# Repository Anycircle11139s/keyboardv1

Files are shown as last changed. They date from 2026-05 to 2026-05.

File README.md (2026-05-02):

# keyboardv1
For hack club stasis, I have to journal a lot, and when I journal, I'm locked in, I just keep on typing and typing until I realise that my hands ache like hell because of my uncomfortable keyboard. Because of this, I decided to make myself a customisable 65% keyboard that I can use for playing games (I can customise the keys and make different modes for what I'm doing), journal and all my other typing needs. I created a keyboard matrix for the schematic and placed all my keys into a specific format in the pcb along with making some stablisation holes for space bars and other keycaps. I also added some tuff af silkscreen to the PCB. For the case, I designed a simple, sleek case which surround the keyboard and has no lid. I made it simplistic but added some small design additions so the keyboard wouldn't get to boring. I also added a small slot to the case of my split keyboard which I can use to attach modules whihc I can design in the future. Overall I am really proud of what I made and can't wait to build it irl.

<br>
Screenshot 2026-05-02 at 12 57 08 pm
<br>

Screenshot 2026-05-02 at 12 57 13 pm
<br>

Screenshot 2026-05-02 at 12 58 45 pm
<br>

Screenshot 2026-05-02 at 12 56 24 pm
<br>

Screenshot 2026-05-02 at 12 56 47 pm
<br>

Screenshot 2026-05-02 at 12 56 58 pm
<br>

Screenshot 2026-05-02 at 12 57 03 pm
<br>
<br>
<br>

BOM:
<br>
<br>

|Name |Purpose |Quantity|Total Cost (USD)|Link |Distributor |
|---|---|---|---|---|---|
|case |the case for the keyboard |1 |10.00 | |printing legion|
|PCB |the pcb for the board |1 |27.84 | |jlcpcb |
|1n4148 diodes |the diodes for keyboard matrix |100 |2.84 |https://www.aliexpress.com/item/1005011766943016.html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 |ali express |
|raspberry pi pico h |the microconrtoller devboard thing|1 |3.00 |https://www.aliexpress.com/item/1005009844027732.html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 |ali express |
|Durock Clear Screw-In Stabilizers|stabilizers for space bar |1 |7.00 |https://www.aliexpress.com/item/1005007236845004.html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 |ali express |
|blue gradient keycaps |switch covers |1 |16.55 |https://www.aliexpress.com/item/1005009032705520.html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|ali express |
|switches |the buttons in keyboard |90 |35.69 |https://www.aliexpress.com/item/1005009496269008.html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 |ali express |

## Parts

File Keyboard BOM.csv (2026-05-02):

Name | Purpose | Quantity | Total Cost (USD) | Link | Distributor
case | the case for the keyboard | 1 | 10.00 |  | printing legion
PCB | the pcb for the board | 1 | 27.84 |  | jlcpcb
1n4148 diodes | the diodes for keyboard matrix | 100 | 2.84 | https://www.aliexpress.com/item/1005011766943016.html?curPageLogUid=WxqQIHnQBOvN | ali express
raspberry pi pico h | the microconrtoller devboard thing | 1 | 3.00 | https://www.aliexpress.com/item/1005009844027732.html | ali express
Durock Clear Screw-In Stabilizers | stabilizers for space bar | 1 | 7.00 | https://www.aliexpress.com/item/1005007236845004.html?curPageLogUid=cq3Hpwq6BscB | ali express
blue gradient keycaps | switch covers | 1 | 16.55 | https://www.aliexpress.com/item/1005009032705520.html?curPageLogUid=8Wpnbc57EDZi | ali express
switches | the buttons in keyboard | 90 | 35.69 | https://www.aliexpress.com/item/1005009496269008.html?curPageLogUid=lkGMG2pIpivm | ali express

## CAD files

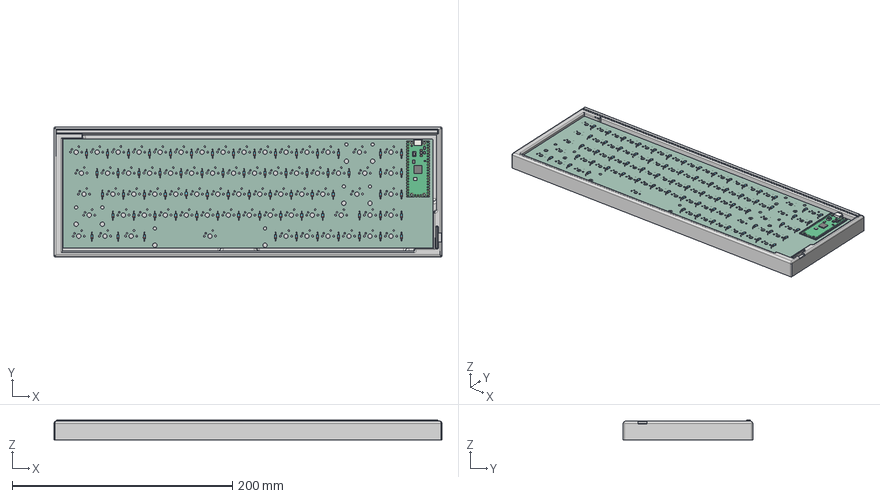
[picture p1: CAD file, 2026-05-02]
keyboard CAD/keyboard final assembly.step
352.1 x 117.7 x 18.0 mm
D_DO-35_SOD27_P7.62mm_Horizontal x 68
RaspberryPi_Pico_Module_KiCad
Mykeyboard_PCB

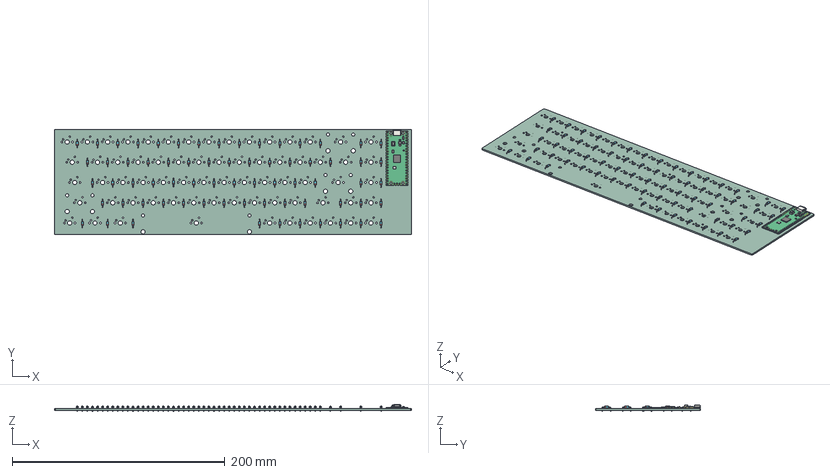
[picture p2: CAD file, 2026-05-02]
keyboard CAD/keyboard pcb.step
335.8 x 99.1 x 6.20 mm
D_DO-35_SOD27_P7.62mm_Horizontal x 68
RaspberryPi_Pico_Module_KiCad
Mykeyboard_PCB

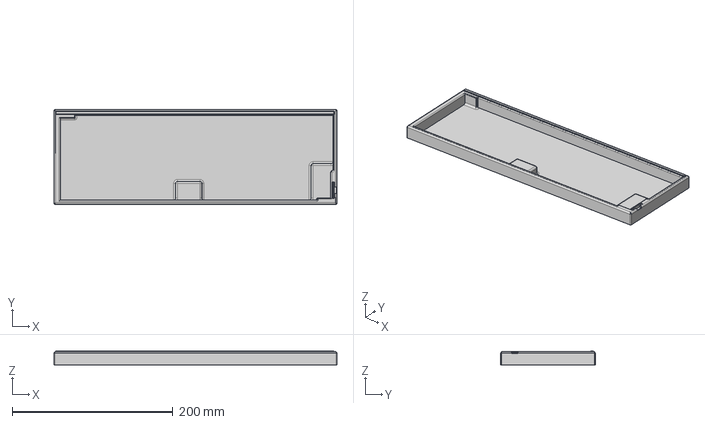
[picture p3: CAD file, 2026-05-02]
keyboard CAD/keyboard case.step
352.1 x 117.7 x 18.0 mm

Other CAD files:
keyboard CAD/keyboard case.3mf
keyboard CAD/keyboard final assembly.3mf
keyboard CAD/keyboard final assembly.f3d

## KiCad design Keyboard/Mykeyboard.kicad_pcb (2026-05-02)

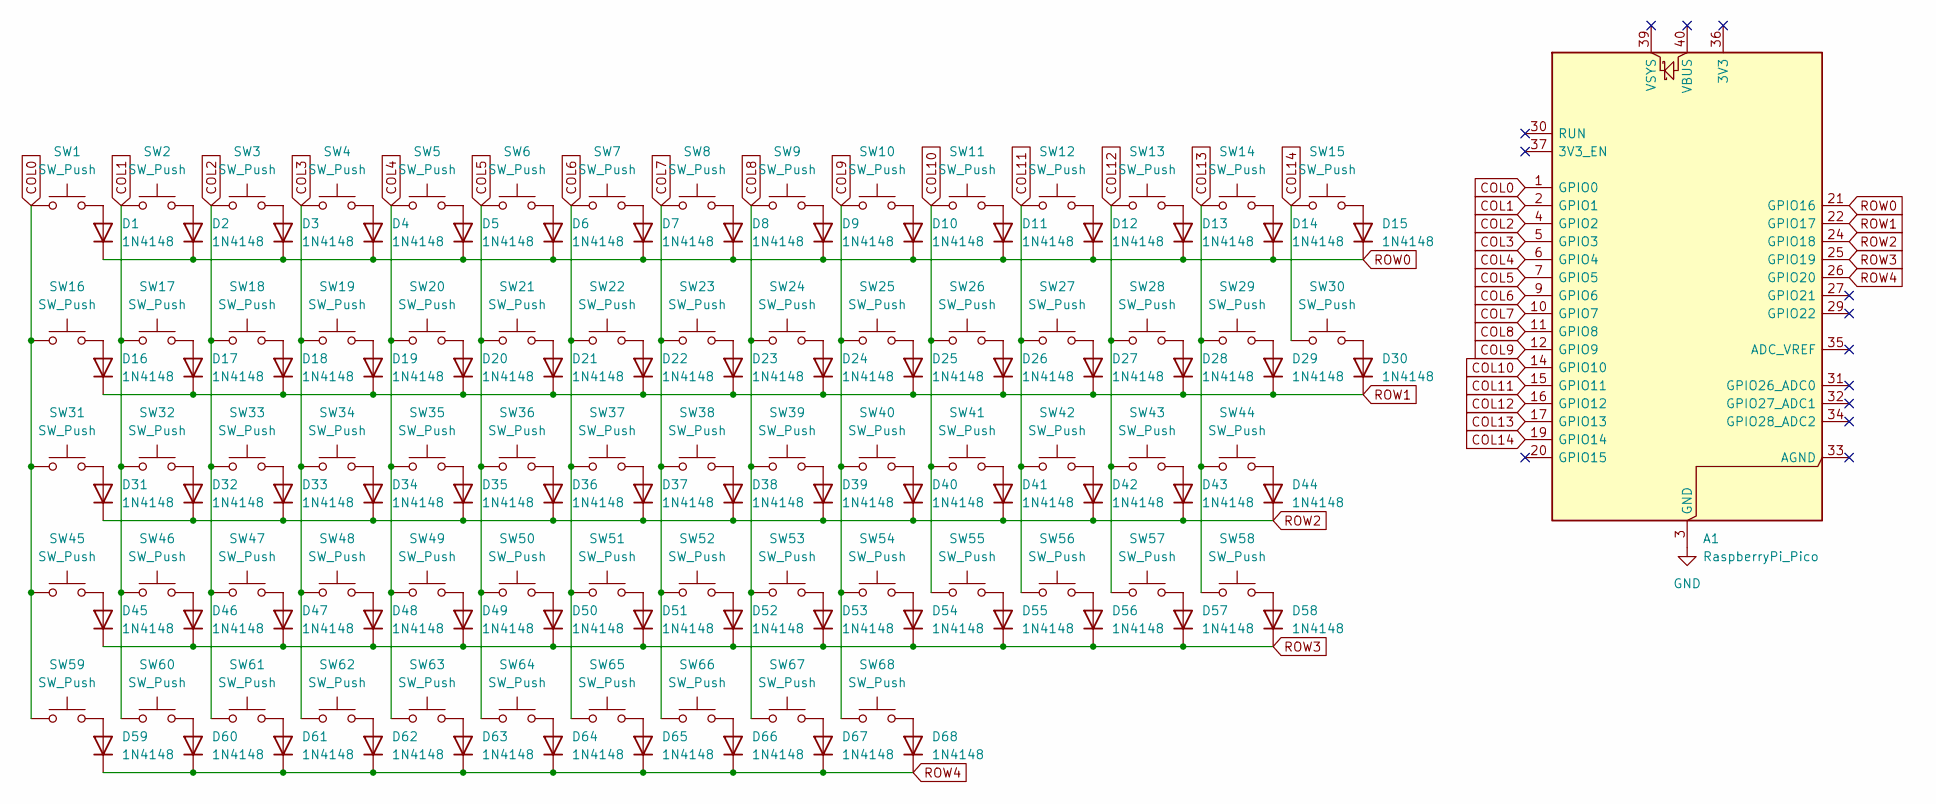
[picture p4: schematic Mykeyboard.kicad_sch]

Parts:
A1: RaspberryPi_Pico; RaspberryPi_Pico_Common_Unspecified
D1, D2, D3, D4, D5, D6, D7, D8, D9, D10, D11, D12, D13, D14, D15, D16, D17, D18, D19, D20, D21, D22, D23, D24, D25, D26, D27, D28, D29, D30, D31, D32, D33, D34, D35, D36, D37, D38, D39, D40, D41, D42, D43, D44, D45, D46, D47, D48, D49, D50, D51, D52, D53, D54, D55, D56, D57, D58, D59, D60, D61, D62, D63, D64, D65, D66, D67, D68: 1N4148; D_DO-35_SOD27_P7.62mm_Horizontal
SW1, SW2, SW3, SW4, SW5, SW6, SW7, SW8, SW9, SW10, SW11, SW12, SW13, SW15, SW17, SW18, SW19, SW20, SW21, SW22, SW23, SW24, SW25, SW26, SW27, SW28, SW30, SW32, SW33, SW34, SW35, SW36, SW37, SW38, SW39, SW40, SW41, SW42, SW44, SW46, SW47, SW48, SW49, SW50, SW51, SW52, SW53, SW54, SW55, SW57, SW58, SW63, SW64, SW65, SW66, SW67, SW68: SW_Push; SW_Cherry_MX_1.00u_PCB
SW14: SW_Push; SW_Cherry_MX_2.00u_PCB
SW16, SW29: SW_Push; SW_Cherry_MX_1.50u_PCB
SW31, SW56: SW_Push; SW_Cherry_MX_1.75u_PCB
SW43, SW45: SW_Push; SW_Cherry_MX_2.25u_PCB
SW59, SW60, SW61: SW_Push; SW_Cherry_MX_1.25u_PCB
SW62: SW_Push; SW_Cherry_MX_6.25u_PCB

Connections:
COL0: A1.1 (GPIO0), SW1.1, SW16.1, SW31.1, SW45.1, SW59.1
COL1: A1.2 (GPIO1), SW2.1, SW17.1, SW32.1, SW46.1, SW60.1
COL2: A1.4 (GPIO2), SW3.1, SW18.1, SW33.1, SW47.1, SW61.1
COL3: A1.5 (GPIO3), SW4.1, SW19.1, SW34.1, SW48.1, SW62.1
COL4: A1.6 (GPIO4), SW5.1, SW20.1, SW35.1, SW49.1, SW63.1
COL5: A1.7 (GPIO5), SW6.1, SW21.1, SW36.1, SW50.1, SW64.1
COL6: A1.9 (GPIO6), SW7.1, SW22.1, SW37.1, SW51.1, SW65.1
COL7: A1.10 (GPIO7), SW8.1, SW23.1, SW38.1, SW52.1, SW66.1
COL8: A1.11 (GPIO8), SW9.1, SW24.1, SW39.1, SW53.1, SW67.1
COL9: A1.12 (GPIO9), SW10.1, SW25.1, SW40.1, SW54.1, SW68.1
COL10: A1.14 (GPIO10), SW11.1, SW26.1, SW41.1, SW55.1
COL11: A1.15 (GPIO11), SW12.1, SW27.1, SW42.1, SW56.1
COL12: A1.16 (GPIO12), SW13.1, SW28.1, SW43.1, SW57.1
COL13: A1.17 (GPIO13), SW14.1, SW29.1, SW44.1, SW58.1
COL14: A1.19 (GPIO14), SW15.1, SW30.1
GND: A1.3 (GND), A1.8 (GND), A1.13 (GND), A1.18 (GND), A1.23 (GND), A1.28 (GND), A1.38 (GND)
unnamed: D1.2 (A), SW1.2
unnamed: D2.2 (A), SW2.2
unnamed: D3.2 (A), SW3.2
unnamed: D4.2 (A), SW4.2
unnamed: D5.2 (A), SW5.2
unnamed: D6.2 (A), SW6.2
unnamed: D7.2 (A), SW7.2
unnamed: D8.2 (A), SW8.2
unnamed: D9.2 (A), SW9.2
unnamed: D10.2 (A), SW10.2
unnamed: D11.2 (A), SW11.2
unnamed: D12.2 (A), SW12.2
unnamed: D13.2 (A), SW13.2
unnamed: D14.2 (A), SW14.2
unnamed: D15.2 (A), SW15.2
unnamed: D16.2 (A), SW16.2
unnamed: D17.2 (A), SW17.2
unnamed: D18.2 (A), SW18.2
unnamed: D19.2 (A), SW19.2
unnamed: D20.2 (A), SW20.2
unnamed: D21.2 (A), SW21.2
unnamed: D22.2 (A), SW22.2
unnamed: D23.2 (A), SW23.2
unnamed: D24.2 (A), SW24.2
unnamed: D25.2 (A), SW25.2
unnamed: D26.2 (A), SW26.2
unnamed: D27.2 (A), SW27.2
unnamed: D28.2 (A), SW28.2
unnamed: D29.2 (A), SW29.2
unnamed: D30.2 (A), SW30.2
unnamed: D31.2 (A), SW31.2
unnamed: D32.2 (A), SW32.2
unnamed: D33.2 (A), SW33.2
unnamed: D34.2 (A), SW34.2
unnamed: D35.2 (A), SW35.2
unnamed: D36.2 (A), SW36.2
unnamed: D37.2 (A), SW37.2
unnamed: D38.2 (A), SW38.2
unnamed: D39.2 (A), SW39.2
unnamed: D40.2 (A), SW40.2
unnamed: D41.2 (A), SW41.2
unnamed: D42.2 (A), SW42.2
unnamed: D43.2 (A), SW43.2
unnamed: D44.2 (A), SW44.2
unnamed: D45.2 (A), SW45.2
unnamed: D46.2 (A), SW46.2
unnamed: D47.2 (A), SW47.2
unnamed: D48.2 (A), SW48.2
unnamed: D49.2 (A), SW49.2
unnamed: D50.2 (A), SW50.2
unnamed: D51.2 (A), SW51.2
unnamed: D52.2 (A), SW52.2
unnamed: D53.2 (A), SW53.2
unnamed: D54.2 (A), SW54.2
unnamed: D55.2 (A), SW55.2
unnamed: D56.2 (A), SW56.2
unnamed: D57.2 (A), SW57.2
unnamed: D58.2 (A), SW58.2
unnamed: D59.2 (A), SW59.2
unnamed: D60.2 (A), SW60.2
unnamed: D61.2 (A), SW61.2
unnamed: D62.2 (A), SW62.2
unnamed: D63.2 (A), SW63.2
unnamed: D64.2 (A), SW64.2
unnamed: D65.2 (A), SW65.2
unnamed: D66.2 (A), SW66.2
unnamed: D67.2 (A), SW67.2
unnamed: D68.2 (A), SW68.2
ROW0: A1.21 (GPIO16), D1.1 (K), D2.1 (K), D3.1 (K), D4.1 (K), D5.1 (K), D6.1 (K), D7.1 (K), D8.1 (K), D9.1 (K), D10.1 (K), D11.1 (K), D12.1 (K), D13.1 (K), D14.1 (K), D15.1 (K)
ROW1: A1.22 (GPIO17), D16.1 (K), D17.1 (K), D18.1 (K), D19.1 (K), D20.1 (K), D21.1 (K), D22.1 (K), D23.1 (K), D24.1 (K), D25.1 (K), D26.1 (K), D27.1 (K), D28.1 (K), D29.1 (K), D30.1 (K)
ROW2: A1.24 (GPIO18), D31.1 (K), D32.1 (K), D33.1 (K), D34.1 (K), D35.1 (K), D36.1 (K), D37.1 (K), D38.1 (K), D39.1 (K), D40.1 (K), D41.1 (K), D42.1 (K), D43.1 (K), D44.1 (K)
ROW3: A1.25 (GPIO19), D45.1 (K), D46.1 (K), D47.1 (K), D48.1 (K), D49.1 (K), D50.1 (K), D51.1 (K), D52.1 (K), D53.1 (K), D54.1 (K), D55.1 (K), D56.1 (K), D57.1 (K), D58.1 (K)
ROW4: A1.26 (GPIO20), D59.1 (K), D60.1 (K), D61.1 (K), D62.1 (K), D63.1 (K), D64.1 (K), D65.1 (K), D66.1 (K), D67.1 (K), D68.1 (K)

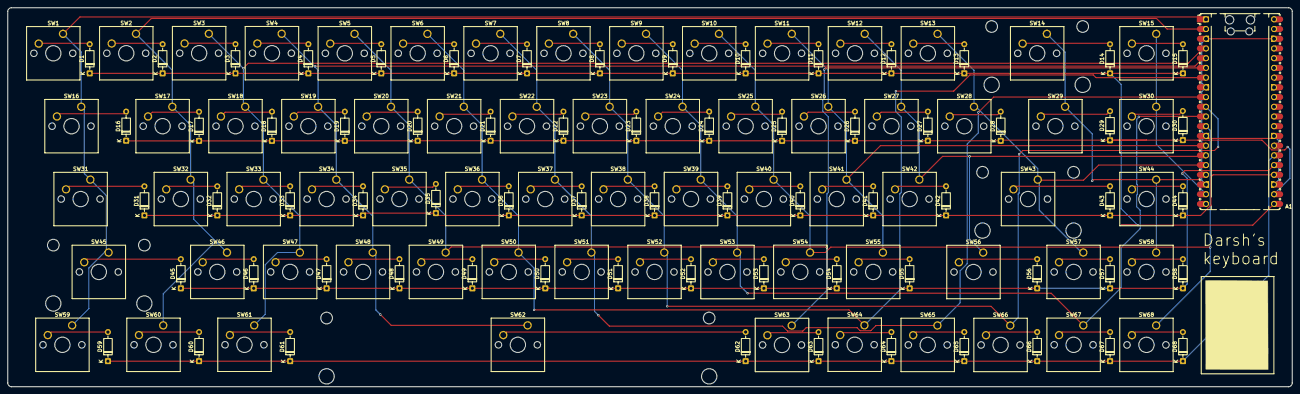
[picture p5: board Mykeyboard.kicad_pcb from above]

Board: 2 copper layers, 335.8 x 99.1 mm, 137 parts (0 on the bottom side), 89 nets.
